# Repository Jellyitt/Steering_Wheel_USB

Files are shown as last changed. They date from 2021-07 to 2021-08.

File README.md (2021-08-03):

# Steering Wheel USB

This repository holds the code and electronics for a USB based steering wheel rim with a dual clutch system. These are used in both this [Formula style rim](https://www.thingiverse.com/thing:4923454) and this [G29 button box mod](https://www.thingiverse.com/).

This is intended to be used with the Arduino Pro Mirco Board. Using the breakout PCB isn't necessary but steering wheels with larger button/switch counts will get messy very quick using the button matix method that the program utilises. If using a different wiring configuration to that of the PCB, insure that all the input pin assignments are changed acordingly. The current wiring is displayed in the figure below. Com1-6 lines are treaded as signal lines to one of the switches/buttons in each group and then each group of switches/buttons has a single common line that connects them all together. This makes up a matrix of buttons/switches, theres a number of guides online that explain it better and have pretty pictures and I would advise you go have a look for yourself. 

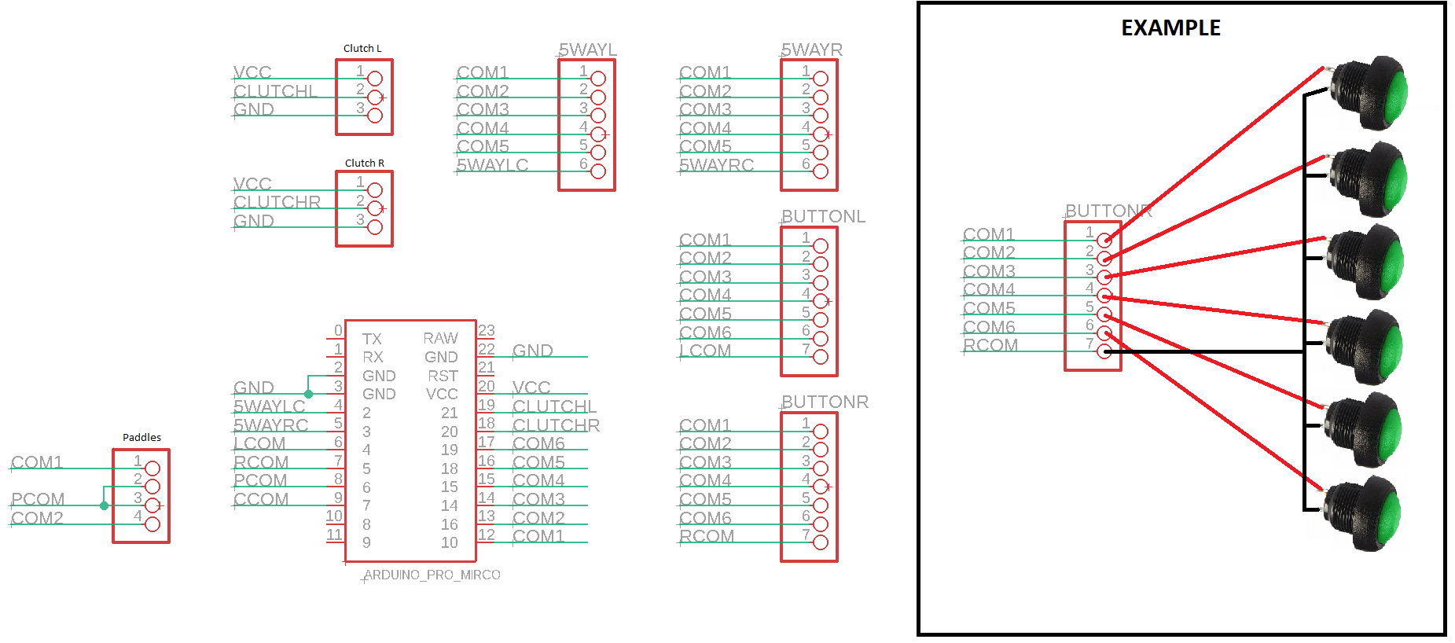
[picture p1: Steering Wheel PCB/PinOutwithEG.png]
Arduino pinout for electronics


The dual clutch system allows for on the fly adjustment of the slave clutch. The clutch adjustment mode can be actived by two buttons held simultaneously or a long hold of a single button. The clutch adjustment can be fine tuned with an adjustable increment (i.e. adjust at ±1% or ±0.1 etc). The buttons used to perform the clutch adjustment can be customised. The clutches will need to have their ranges calculated to be accuate but a program is include with instructions in the code.   

No further devolopment will be done on this version.

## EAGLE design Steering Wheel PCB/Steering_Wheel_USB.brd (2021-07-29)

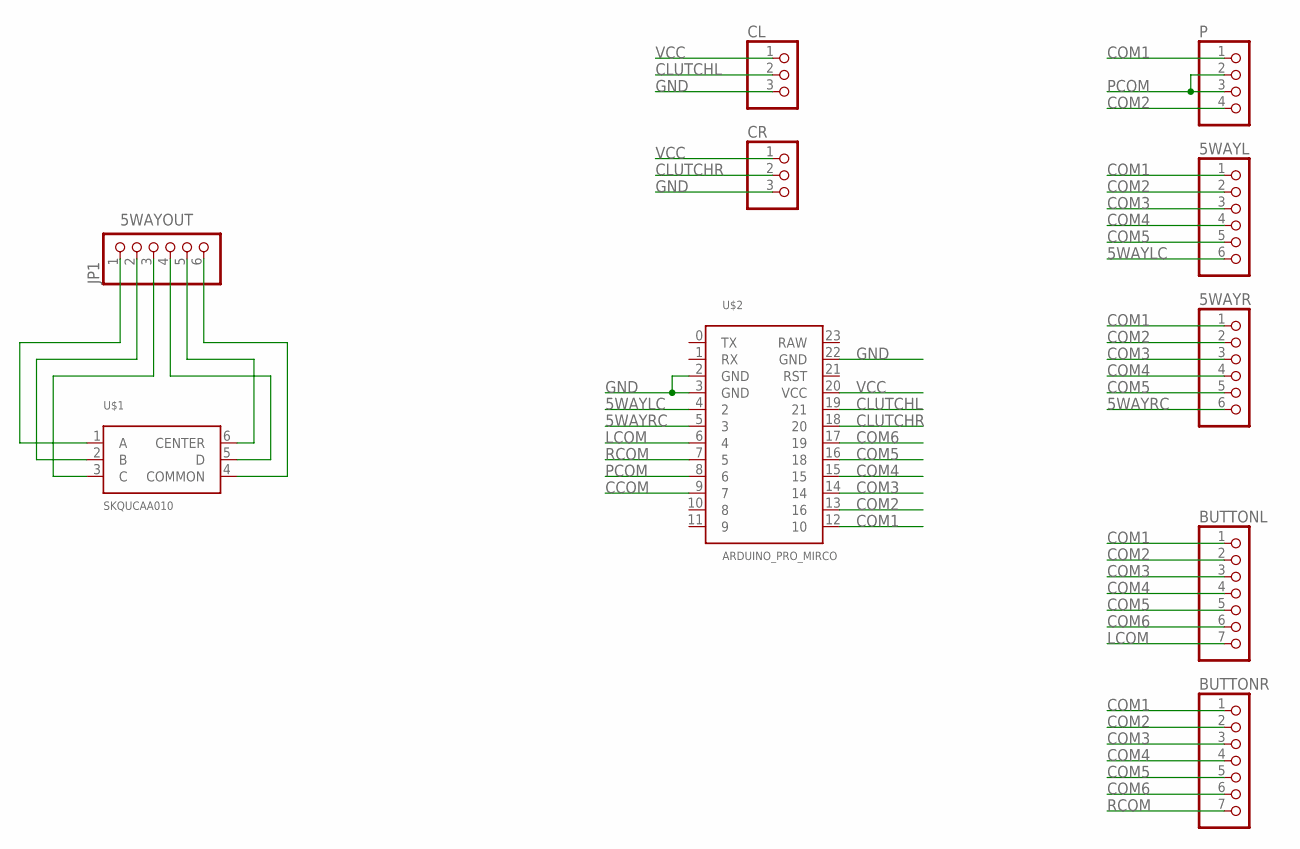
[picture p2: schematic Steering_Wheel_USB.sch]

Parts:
5WAYL, 5WAYR: PINHD-1X6; 1X06
BUTTONL: PINHD-1X7; 1X07
BUTTONR: PINHD-1X7; 1X07
CL: PINHD-1X3; 1X03
CR: PINHD-1X3; 1X03
JP1: PINHD-1X6; 1X06
P: PINHD-1X4; 1X04
U$1: SKQUCAA010
U$2: ARDUINO_PRO_MIRCO; ARDUINO_PRO_MICRO

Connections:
5WAYLC: 5WAYL.6, U$2.4 (2)
5WAYOUT: JP1.1, U$1.1 (A)
5WAYRC: 5WAYR.6, U$2.5 (3)
CCOM: U$2.9 (7)
CLUTCHL: CL.2, U$2.19 (21)
CLUTCHR: CR.2, U$2.18 (20)
COM1: 5WAYL.1, 5WAYR.1, BUTTONL.1, BUTTONR.1, P.1, U$2.12 (10)
COM2: 5WAYL.2, 5WAYR.2, BUTTONL.2, BUTTONR.2, P.4, U$2.13 (16)
COM3: 5WAYL.3, 5WAYR.3, BUTTONL.3, BUTTONR.3, U$2.14
COM4: 5WAYL.4, 5WAYR.4, BUTTONL.4, BUTTONR.4, U$2.15
COM5: 5WAYL.5, 5WAYR.5, BUTTONL.5, BUTTONR.5, U$2.16 (18)
COM6: BUTTONL.6, BUTTONR.6, U$2.17 (19)
GND: CL.3, CR.3, U$2.2 (GND), U$2.3 (GND), U$2.22 (GND)
LCOM: BUTTONL.7, U$2.6 (4)
unnamed: JP1.2, U$1.2 (B)
unnamed: JP1.3, U$1.3 (C)
unnamed: JP1.4, U$1.5 (D)
unnamed: JP1.5, U$1.6 (CENTER)
unnamed: JP1.6, U$1.4 (COMMON)
PCOM: P.2, P.3, U$2.8 (6)
RCOM: BUTTONR.7, U$2.7 (5)
VCC: CL.1, CR.1, U$2.20 (VCC)

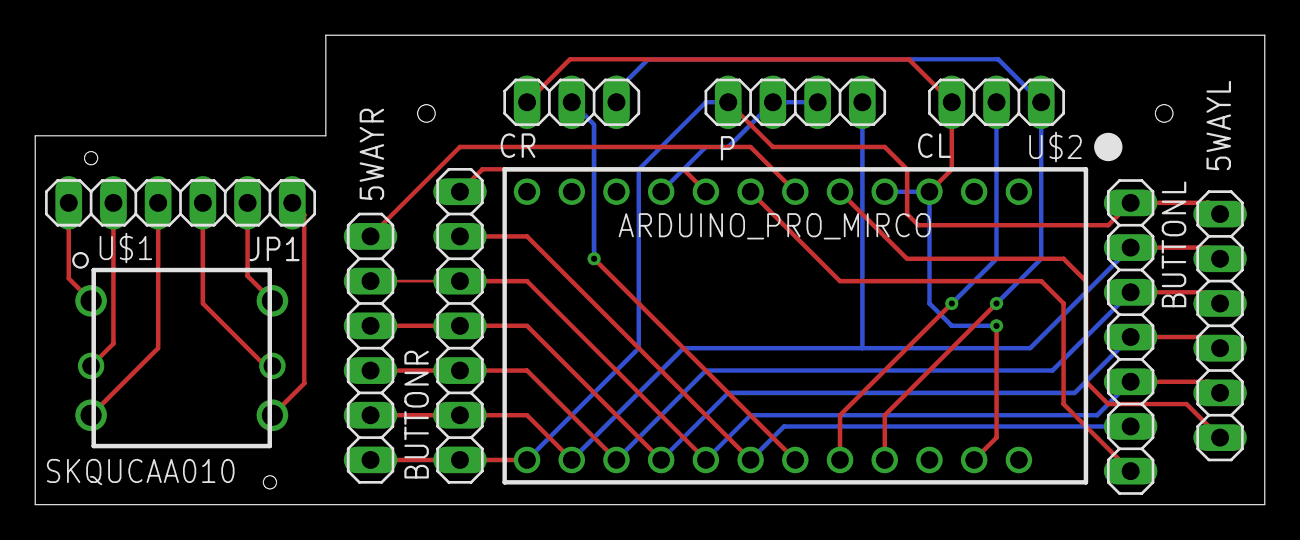
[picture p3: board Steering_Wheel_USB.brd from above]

Board: 2 copper layers, 69.8 x 26.7 mm, 10 parts (0 on the bottom side), 21 nets.

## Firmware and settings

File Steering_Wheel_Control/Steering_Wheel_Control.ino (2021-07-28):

#include <Joystick.h> //  [https://github.com/MHeironimus/ArduinoJoystickLibrary]
#include <Keypad.h>
#include <EEPROM.h>

/*----------------------- These values should be customised to liking, current values my not work out of the box------------------
*
*Best way to select your own buttons is to use windows game controller settings input preview or a gamepad tester website to see 
*how the buttons are mapped. Load this code onto your board and just start pressing buttons. See what value comes up for the 
*button you want to use and input that value below.
*
*Potentiometer ranges should be checked after clutch assembly using the clutch range program and then inputted below.
*/ 

// buttons held together to arm clutch adjust mode, program doesn't block these from sending to pc when pushed so care for unintentional commands
#define CLUTCH_ADJ_BUTTON_1 18 
#define CLUTCH_ADJ_BUTTON_2 19

#define INCREASE_BUTTON 7 // changes the slv clutch multipler value (bite adjust) 
#define DECREASE_BUTTON 22
#define ADJ_INCRMT_INCREASE_BUTTON 16 // changes the adjustment increment 
#define ADJ_INCRMT_DECREASE_BUTTON 1

#define MSTR_POT_MAX 538 // master clutch potentiometer movement range 
#define MSTR_POT_MIN 470

#define SLV_POT_MAX 730 // slave clutch potentiometer movement range
#define SLV_POT_MIN 650
//--------------------------------------------------------------------------------------------------------------------------------


// swap these two numbers around below if you want to swap which clutch is which
#define SLV_PIN 21 // slave clutch signal pin
#define MSTR_PIN 20 // master clutch signal pin

#define BITE_ADJ_MAX 0.95 // range for the slv clutch multipler
#define BITE_ADJ_MIN 0.05

#define ENABLE_PULLUPS
#define NUMBUTTONS 30 // pcb allows 30 buttons but not all need to be used 
#define NUMROWS 6
#define NUMCOLS 5


int addr = 1;

float slvValue = 0;
float mstrValue = 0;

double slvRead = 0;
double mstrRead = 0;

float sendValue = 0;

float biteAdjust = 0.4;
float adjustIncrement = 0.01;

bool clutchCalabration = false;
char currentPressedChar;
int calaSeen = 0;

byte buttons[NUMROWS][NUMCOLS] = { // buttons map to chars
  {0, 1, 2, 3, 4},
  {5, 6, 7, 8, 9},
  {10, 11, 12, 13, 14},
  {15, 16, 17, 18, 19},
  {20, 21, 22, 23, 24},
  {25, 26, 27, 28, 29}
};


byte rowPins[NUMROWS] = {10, 16, 14, 15, 18, 19}; // data pins
byte colPins[NUMCOLS] = {2, 3, 4, 5, 6}; // common pins

Keypad butts = Keypad( makeKeymap(buttons), rowPins, colPins, NUMROWS, NUMCOLS);

Joystick_ Joystick(JOYSTICK_DEFAULT_REPORT_ID, JOYSTICK_TYPE_JOYSTICK, NUMBUTTONS, 0, true, false, false, false, false, false, false, false, false, false, false);
                  // make joystick with buttons and X axis


void CheckClutchAdjust(int butNum)  // checks for button presses for adjusting the slave clutch
{
  char pressed = butts.key[butNum].kchar;
  if (pressed == (INCREASE_BUTTON - 1)) 
  {
    biteAdjust = biteAdjust + adjustIncrement;
    if(biteAdjust > BITE_ADJ_MAX) //increased past slave clutch max so set to max
    {
      biteAdjust = BITE_ADJ_MAX;
    }    
  }
  else if (pressed == (DECREASE_BUTTON - 1))
  {
    biteAdjust = biteAdjust - adjustIncrement;
    if(biteAdjust < BITE_ADJ_MIN) //decreased past slave clutch min so set to min
    {
      biteAdjust = BITE_ADJ_MIN;
    }    
  }
  else if (pressed == (ADJ_INCRMT_INCREASE_BUTTON - 1))//increase adjustment incremnet
  {
    adjustIncrement = adjustIncrement * 10;    
  }
  else if (butNum == (ADJ_INCRMT_DECREASE_BUTTON - 1))//decrease adjustment incremnet
  {
    adjustIncrement = adjustIncrement / 10;    
  }
  else // inputs made during clutch adjustment not for adjustment don't get blocked to the computer 
  {  
    Joystick.setButton(pressed, 1); 
  }
  
  
}

void CheckClutch(void) // handles reading, operations and setting clutchs
{
  mstrValue = map(analogRead(MSTR_PIN), MSTR_POT_MIN, MSTR_POT_MAX, 1023, 0); // read master clutch and map to 0 - 1023 range, pot max min range need to be set to get good readings
  
  slvRead = map(analogRead(SLV_PIN), SLV_POT_MIN, SLV_POT_MAX, 0, 1023); // read slave clutch and map to 0 - 1023 range, pot max min range need to be set to get good readings
  slvValue = slvRead * biteAdjust; // uses the clutch mutlipler to set clutch travel for slave clutch
  
  if (mstrValue > slvValue) // determines what clutch value to use (largest value is always used)
  {
    Joystick.setXAxis(mstrValue);
  }
  else
  {
    Joystick.setXAxis(slvValue);
  }  
}


void CheckAllButtons(void) 
{
  if (butts.getKeys()) 
  {
    for (int i = 0; i < LIST_MAX; i++)
    {
      if (butts.key[i].stateChanged )
      {
         switch (butts.key[i].kstate) 
         {
          case PRESSED:
            if (clutchCalabration)
            {              
              CheckClutchAdjust(i);
            }
            else
            {
              Joystick.setButton(butts.key[i].kchar, 1);              
            }
            
            break;
          case HOLD:
            currentPressedChar = butts.key[i].kchar;

            if (currentPressedChar == (CLUTCH_ADJ_BUTTON_1 - 1) || currentPressedChar == (CLUTCH_ADJ_BUTTON_2 - 1)) // Uses look left and look right together
            {
              calaSeen++; // when @ 2 we know we've seen both button holds or one button held for 2 cycles
              
            }
            Joystick.setButton(currentPressedChar, 1);
            
            break;
          case RELEASED:
          case IDLE:
            Joystick.setButton(butts.key[i].kchar, 0);
            break;
        }
      }
    }
    if (calaSeen == 2) // when @ 2 we know we've seen both button holds or one held for 2 cycles, the 2 could be increased if you want longer holds to engage/ disengage the calabration mode
    {
      //Joystick.setButton(29, 1); // to digitally show clutch adjust state
      if (clutchCalabration)
      {
        adjustIncrement = 0.1; // resets the adjustment increment when disarming clutch calabration
        EEPROM.write(addr,biteAdjust); // save the slave clutch multipler to eeprom 

        //Joystick.setButton(29, 0); // to digitally show clutch adjust state
      }
      clutchCalabration = !clutchCalabration;
    }
    calaSeen = 0;
  }
}




void setup() 
{
  pinMode(MSTR_PIN, INPUT); // setup clutch inputs
  pinMode(SLV_PIN, INPUT);

  biteAdjust = EEPROM.read(addr); // read the maximum slave clutch value

  if (biteAdjust > BITE_ADJ_MAX || biteAdjust < BITE_ADJ_MIN) // check that what is read from eeprom is what we want 
  {
    biteAdjust = 0.4; // set to default when biteAdjust is read as out of bounds on start up
  }

  Joystick.begin();  
}

void loop() 
{
  CheckAllButtons();
  CheckClutch();
}

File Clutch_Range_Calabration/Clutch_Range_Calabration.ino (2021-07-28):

/* Load this onto the board to find the potentiometer ranges for the master and slave clutch.
*  While the board is pluged in open the serial monitor to display the values.
*  Move the clutch levers through their full ranges while running the program.
*  Make sure that there are no big jumps in the current values which would likely indicate that
*  there is a bad conection between the potentiometer and the control board. 
*  After doing a few full sweeps of both clutch assemblies the board can then be disconected 
*  and the Max and Min range values can be copied into the steering wheel control code  
*  where the they are set (between the doted lines towards the top).
*/

#define MSTR_PIN 20
#define SLV_PIN 21

int mstrMax = 0;
int mstrMin = 9999;

int slvMax = 0;
int slvMin = 9999;

char mstrBuff[50];
char slvBuff[50];

void setup() 
{     
  pinMode(MSTR_PIN, INPUT);
  pinMode(SLV_PIN, INPUT);

  Serial.begin(9600);
}

void loop() 
{
  int mstrCurrent = analogRead(MSTR_PIN);
  int slvCurrent = analogRead(SLV_PIN);

  if(mstrCurrent > mstrMax){mstrMax = mstrCurrent;}
  if(mstrCurrent < mstrMin){mstrMin = mstrCurrent;}
  if(slvCurrent > slvMax){slvMax = slvCurrent;}
  if(slvCurrent < slvMin){slvMin = slvCurrent;}

  sprintf(mstrBuff, "Master Current: %d Max: %d Min: %d", mstrCurrent, mstrMax, mstrMin);
  sprintf(slvBuff, "Slave Current: %d Max: %d Min: %d", slvCurrent, slvMax, slvMin);

  Serial.println(mstrBuff);
  Serial.println(slvBuff);
  Serial.println("----------------------------------------");
    
}
